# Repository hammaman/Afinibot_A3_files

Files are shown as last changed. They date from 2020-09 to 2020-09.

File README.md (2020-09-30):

# Afinibot_A3_files

The Afinibot A3 3D printer is a 3D printer in acrylic which has been classified as a Migbot Prusa i3 variant (see https://reprap.org/wiki/Migbot_Prusa_i3).

It appears to use a Melzi controller board (see https://www.reprap.org/wiki/Melzi).

Repository for Afinibot A3 files:
 - Original build instructions
 - FTDI USB drivers
  - A3 firmware from Afinibot forum (https://www.robotshop.com/community/forum/t/3d-printer-firmware/26569)

Plus additional STL files from redesign of X-Axis parts (based on those for Prusa i3 MK3S)

# Other useful information

I have found some firmware which I have not reviewed in a Github repository at https://github.com/Octane70/Repetier-Firmware-0.92.X.

There are some wordpress articles at https://electronicgeektips.wordpress.com/prusa-i3-auto-level-troubleshooting/

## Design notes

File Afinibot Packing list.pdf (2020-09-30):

Category | Name | Unit

Framework

Framework (Middle) | 1pcs | □ □
Framework (Left) | 1pcs | □ □
Framework (Right) | 1pcs | □ □
Base Frame Holder (Front) | 1pcs | □ □
Base Frame Holder (Back) | 1pcs | □ □
Framework Holder (top) | 2pcs | □ □
LCD Display Holder | 1pcs | □ □
Sliding Rod Restriction | 6pcs | □ □
Heating End | Print Platform (Assembled) Extruder (Assembled) | 1pcs 1pcs | □ □ □ □
X-axis | X-axis Motor Mount X-axis Pulley Mount X-axis Sliding Rod (Φ8/ 448mm) X-axis Timing Belt X-xis Limit Switch | 1set 1set 2pcs 1pcs 1pcs | □ □ □ □ □ □ □ □ □ □
Category | Name | Unit

Y-axis

Y-axis Motor Support | 1pcs | □ □
Y-axis Motor Holder | 1pcs | □ □
Y-axis Limit Switch Holder | 1pcs | □ □
Y-axis Motor(with 2GT Gear) | 1set | □ □
Y-axis Sliding Rod (Φ8/380mm) | 2pcs | □ □
Y-axis Limit Switch | 1pcs | □ □
Y-axis Timing Belt | 1pcs | □ □
Y-axis Belt Pulley Wheel | 1set | □ □

Z-axis

Z-axis Motor Support(Side) | 4pcs | □ □
Z-axis Motor Support(Top) | 2pcs | □ □
Z-axis Motor (With coupling) | 2pcs | □ □
Z-axis Screw Arbor (M8/322mm) | 2set | □ □
Z-axis Sliding Rod(Φ8/350mm) | 2pcs | □ □
Z-axis Limit Switch | 1pcs | □ □
Display | LCD Display & Key-press | 1set | □ □

Afinibot A3 3D printer part list

Electronic | Control Board Power Supply | 1pcs 1pcs | □ □ □ □
Wiring | DC Power Wire (Red&Black) Motor Wire X-axis limit switch Wire Y-axis limit switch Wire Z-axis limit switch Wire | 2pcs 4pcs 1pcs 1pcs 1pcs | □ □ □ □ □ □ □ □ □ □
Feeding Support | Frame Fixed Link Filament Support Frame Filament Support Tube | 2pcs 2pcs 1pcs | □ □ □ □ □ □

Accessory

Screw Arbor (Base) M8/400mm | 2pcs | □ □
TUS (M8/Transparent) | 5pcs | □ □
Copper Pillar | 4pcs | □ □
Flat-heat Cross-screw(M3*14mm) | 13pcs | □ □
Flat-heat Cross-screw(M3*20mm) | 2pcs | □ □
Round Head Screw(M3*20mm) | 46pcs | □ □
Inner Hexagon Screw(M3*10mm) | 15pcs | □ □
Inner Hexagon Screw(M3*20mm) | 3pcs | □ □
Inner Hexagon Screw(M3*30mm) | 2pcs | □ □
Tapping Screw(Black ,M2*14mm) | 2pcs | □ □
Nut (M8) | 12pcs | □ □
Nut (M3) | 45set | □ □
Cushion Ring (M8) | 12pcs | □ □
Cushion Ring (M3) | 10pcs | □ □
Nylon Cable Ties (Length 120mm) | 8pcs | □ □

Tools

USB Cable (150cm) | 1pcs | □ □
TF Card (4GB) | 1pcs | □ □
Tweezers | 1pcs | □ □
Diagonal Pliers | 1pcs | □ □
Hexagon Socket Key | 1set | □ □
Flat Blade Screwdriver | 1pcs | □ □
Crosshead Screwdriver | 1pcs | □ □

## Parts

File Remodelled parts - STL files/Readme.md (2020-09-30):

# Remodelled parts

The X-Axis left and right hand side parts supplied were not very good; and had cracked on my printer (probably as a result of having the extruder too low).

I have designed new parts (as I cannot find the original STL files anywhere online), based on the models for the Prusa i3 MK3S.

The Prusa i3 MK3S models are taken from https://www.prusa3d.com/prusa-i3-printable-parts/ and subject to the GNU GPL v3 licence.  These models have been adjusted for my personal use, and are shared subject to the terms of the licence.

The main adjustments made are as follows:
- the right hand x-axis idler is designed so that the two rods pass completely through it.  The holes may need to be slightly widened to make a tight fit, but also allow the rods to slide through without too much effort.
- a new part has been designed to attach to the right of the x-axis idler to hold the rods steady.  This connects using a M3 screw (30mm or longer) and a square M3 nut inserted into the slot in the x-axis idler.
- the left hand x-axis motor is designed so that the belt is set up quite tight, and then can be adjusted by inserting a M3 screw in the top.

As a result of the new parts, the alignment of the belt is slightly different:
- A new part is required to be inserted on the back of the extruder where the belt is attached, so that the belt runs in the same plane as the rods.
- Also, the z-axis switch needs to be further away from the frame, and a new part is required to act as a spacer.

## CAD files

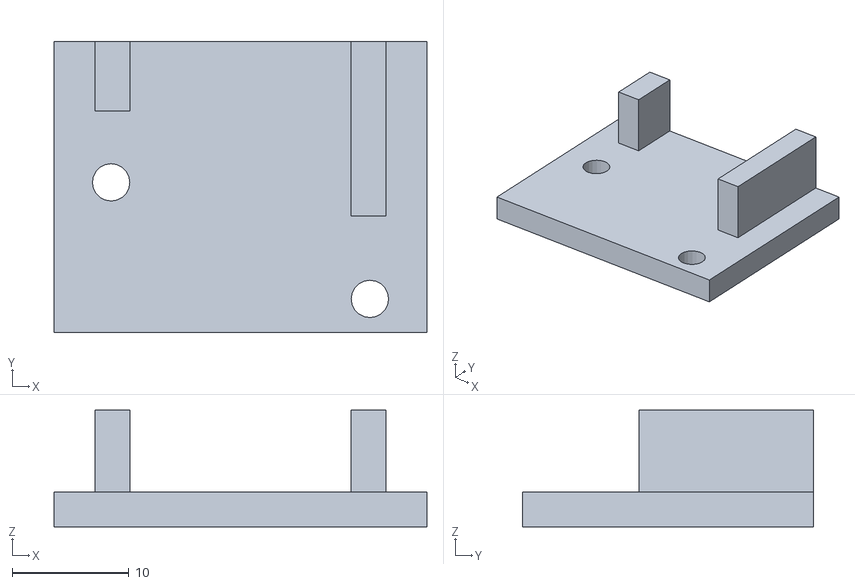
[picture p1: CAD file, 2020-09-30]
Remodelled parts - STL files/v3 Z Axis Switch Mount.stl
32.0 x 25.0 x 10.0

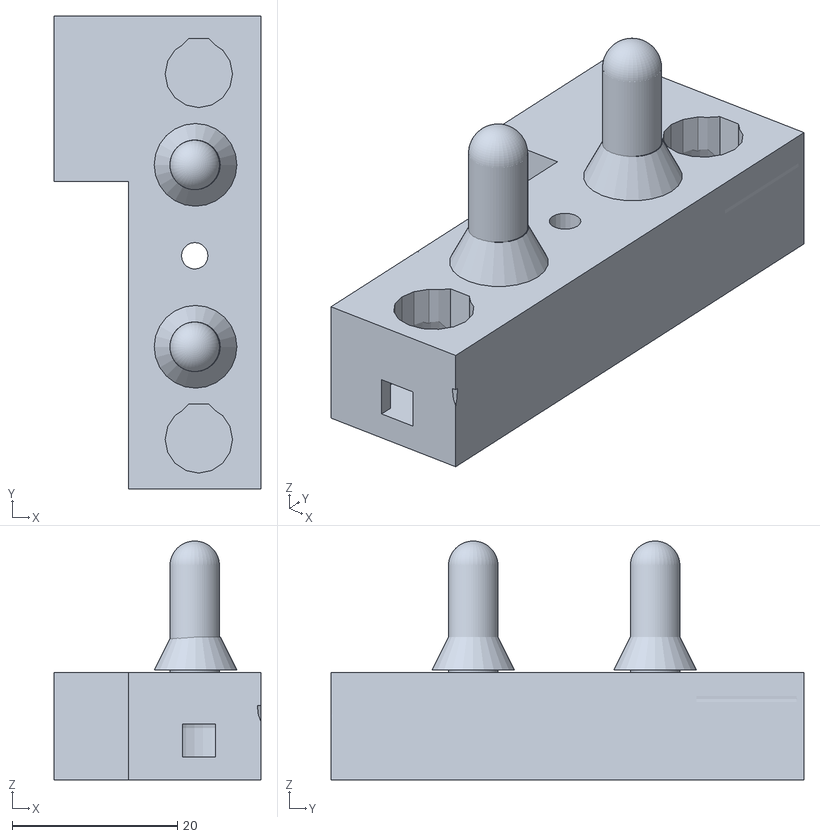
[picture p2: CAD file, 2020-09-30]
Remodelled parts - STL files/v3 End stop for X Idler with laser mount.stl
25.0 x 57.2 x 28.9

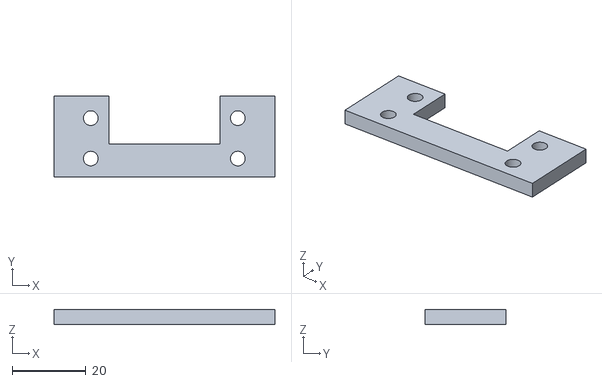
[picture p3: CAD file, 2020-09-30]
Remodelled parts - STL files/3D printer spacer v3.stl
60.1 x 22.0 x 4.00

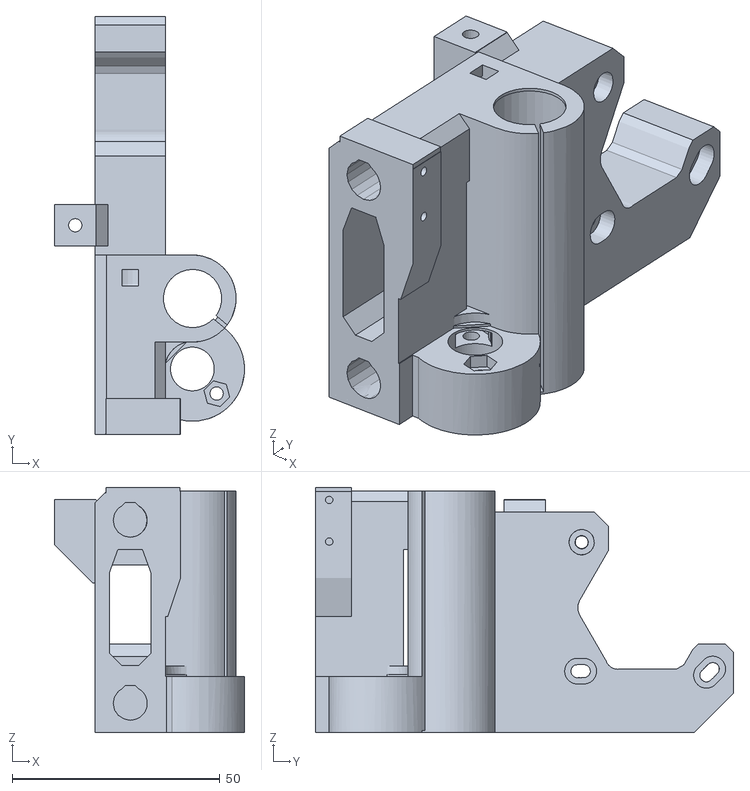
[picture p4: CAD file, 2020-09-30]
Remodelled parts - STL files/v6 Adjusted Prusa i3 X Motor.stl
45.7 x 100.5 x 58.9

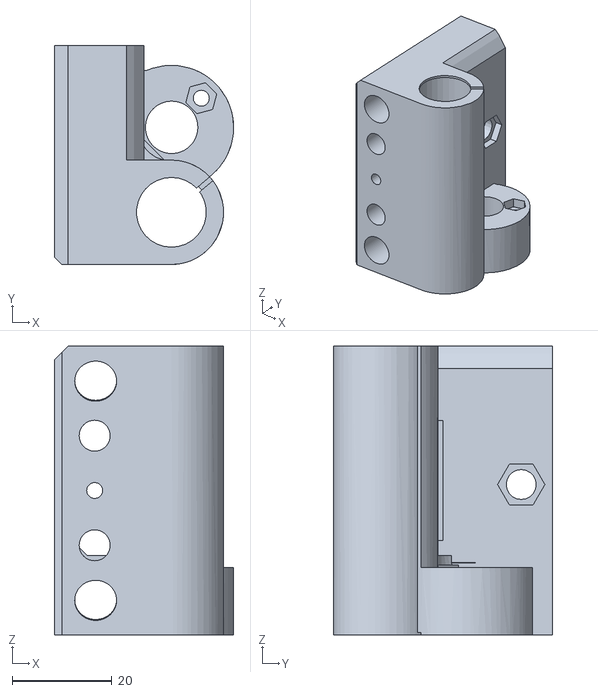
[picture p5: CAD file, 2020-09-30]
Remodelled parts - STL files/v7 Adjusted Prusa i3 x-axis idler.stl
36.0 x 44.0 x 58.0

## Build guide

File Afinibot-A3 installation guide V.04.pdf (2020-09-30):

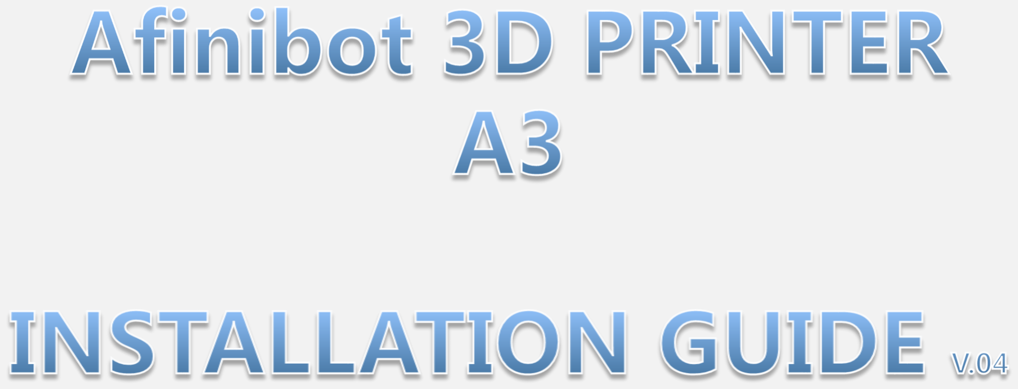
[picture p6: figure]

## Classification Of Screws

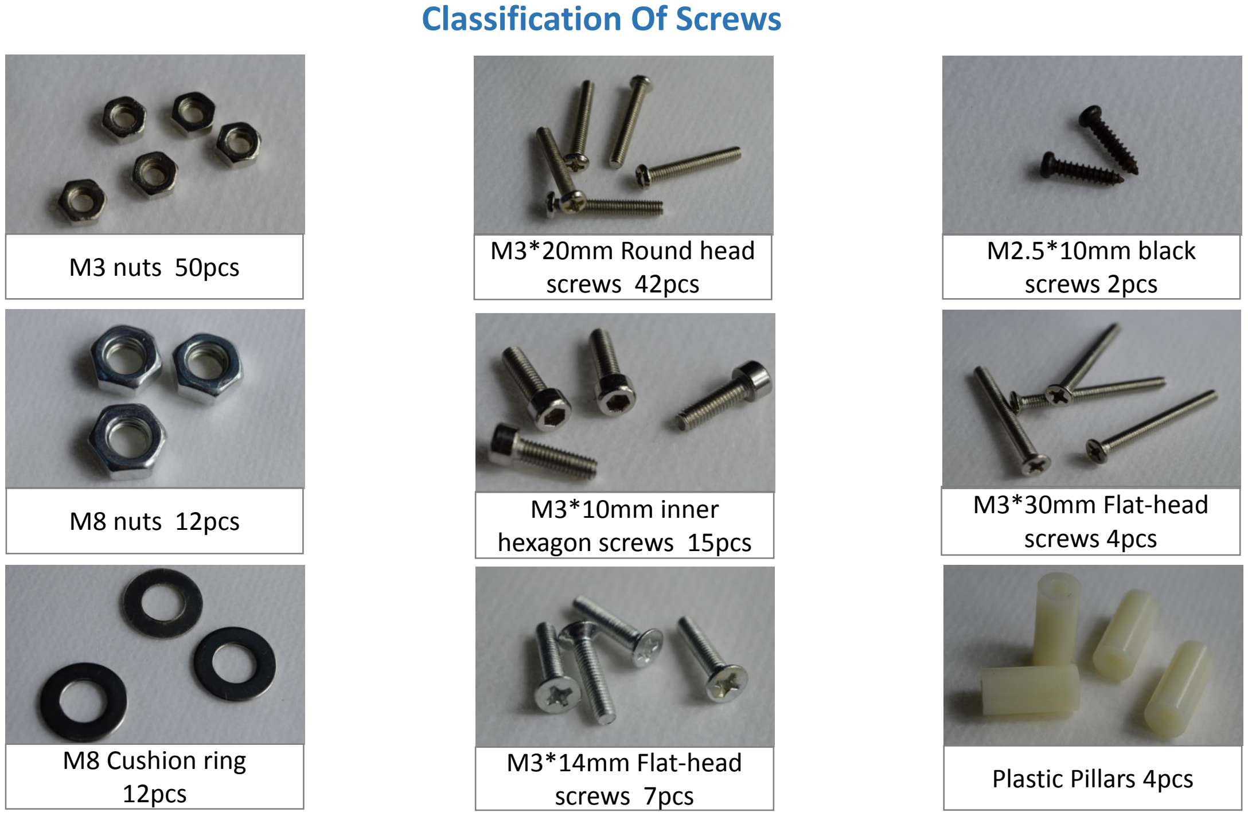
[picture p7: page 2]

M3 nuts 50pcs | M3*20mm Round head screws 42pcs

M2.5*10mm black
screws 2pcs

M3*10mm inner
hexagon screws 15pcs

M8 nuts 12pcs

M8 Cushion ring
12pcs | Plastic Pillars 4pcs M3*14mm Flat-head
screws 7pcs

M3*30mm Flat-head
screws 4pcs

## Step 1 Assemble Y-axis Motor

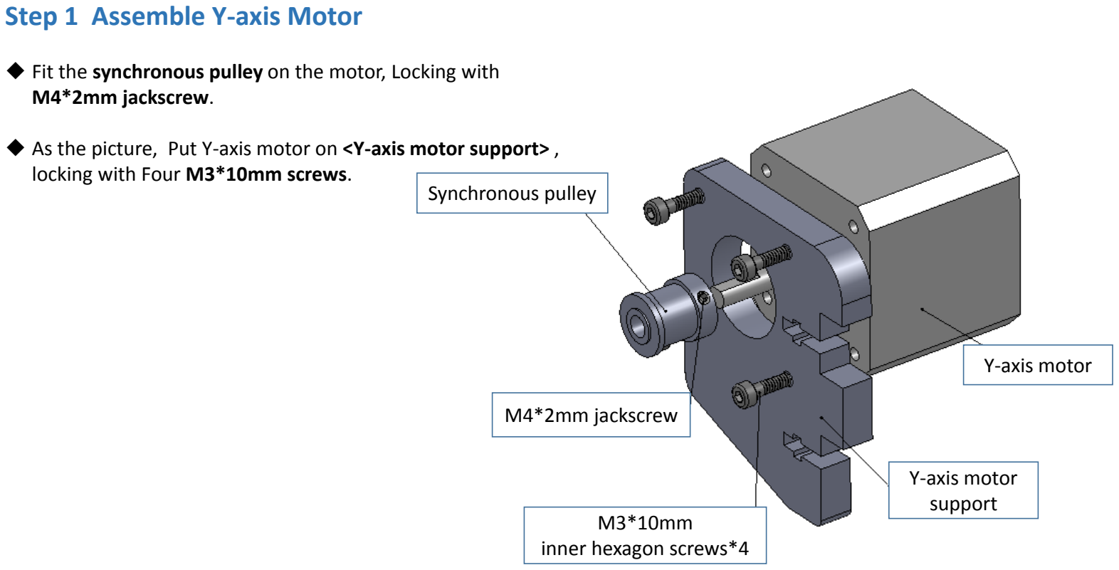
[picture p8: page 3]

M3*10mm
inner hexagon screws*4

Y-axis motor
support

Y-axis motor

M4*2mm jackscrew

Synchronous pulley

- Fit the synchronous pulley on the motor, Locking with M4*2mm jackscrew.
- As the picture, Put Y-axis motor on <Y-axis motor support> , locking with Four M3*10mm screws.

## Step 2 Assemble Y-axis Limit switch

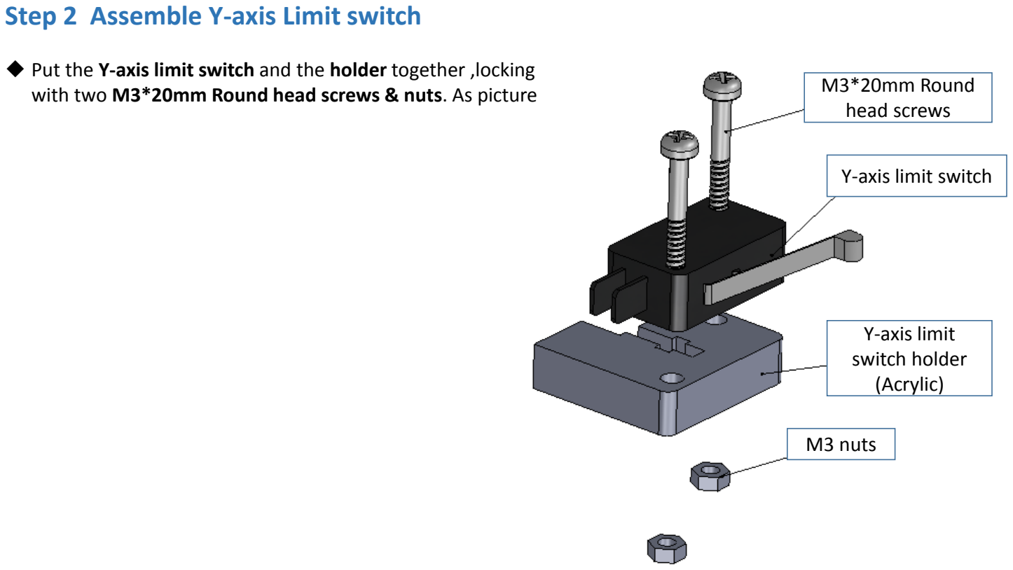
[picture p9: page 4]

- Put the Y-axis limit switch and the holder together ,locking
with two M3*20mm Round head screws & nuts. As picture | M3*20mm Round
| head screws
| Y-axis limit switch

Y-axis limit
switch holder
(Acrylic)

M3 nuts

## Step 3 Assemble Base Frame Holder_Back

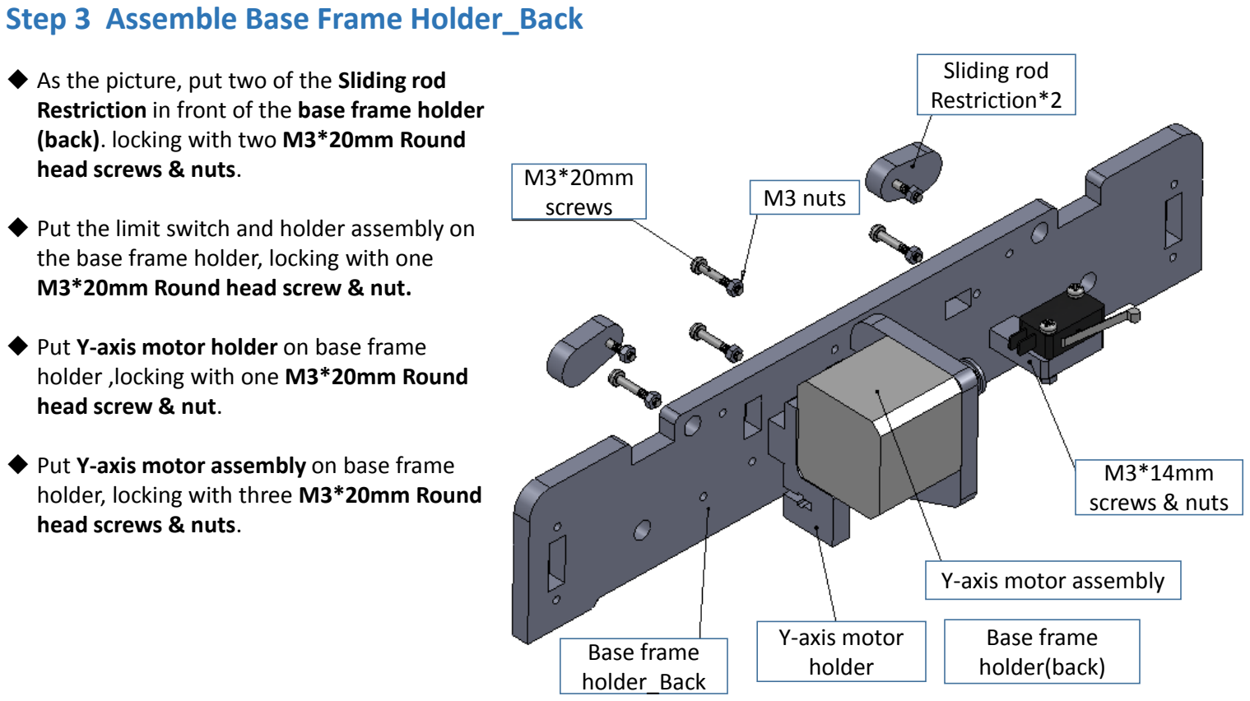
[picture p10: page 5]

Y-axis motor assembly

Base frame
holder(back)

Sliding rod
Restriction*2

M3*20mm
screws

M3*14mm
screws & nuts

Y-axis motor
holder Base frame
holder_Back

M3 nuts

- As the picture, put two of the Sliding rod Restriction in front of the base frame holder (back). locking with two M3*20mm Round head screws & nuts.
- Put the limit switch and holder assembly on the base frame holder, locking with one M3*20mm Round head screw & nut.
- Put Y-axis motor holder on base frame holder ,locking with one M3*20mm Round head screw & nut.
- Put Y-axis motor assembly on base frame holder, locking with three M3*20mm Round head screws & nuts.

## Step 4 Assemble Base Frame Holder_Front

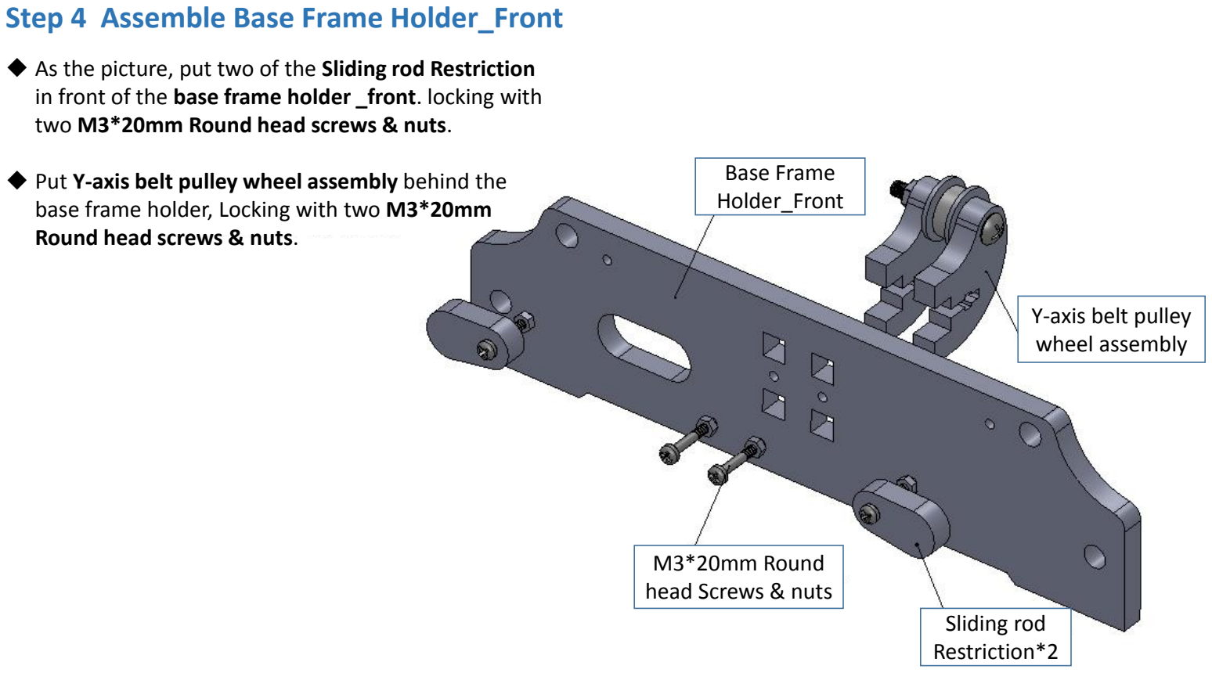
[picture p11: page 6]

Sliding rod
Restriction*2

M3*20mm Round
head Screws & nuts

Y-axis belt pulley
wheel assembly

Base Frame
Holder_Front
- As the picture, put two of the Sliding rod Restriction in front of the base frame holder _front. locking with two M3*20mm Round head screws & nuts.
- Put Y-axis belt pulley wheel assembly behind the base frame holder, Locking with two M3*20mm Round head screws & nuts.

## Step 5 Assemble Z-axis motor

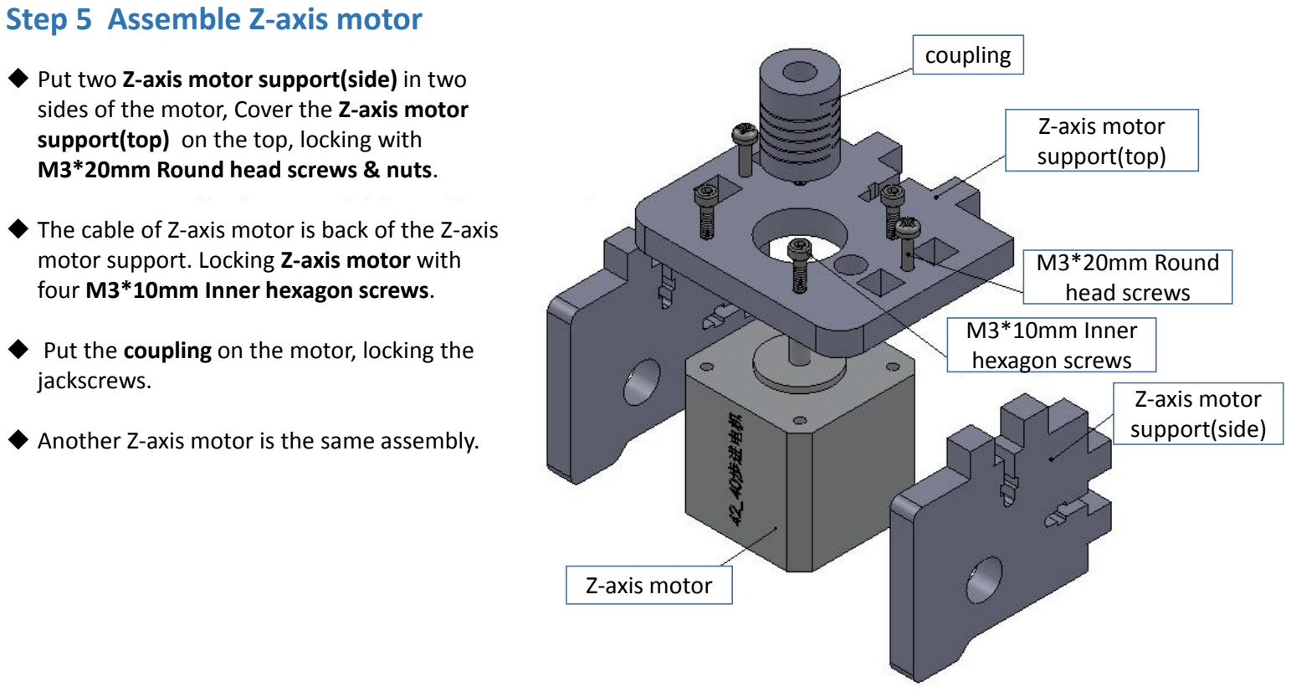
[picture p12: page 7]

coupling

M3*20mm Round
head screws
M3*10mm Inner
hexagon screws
Z-axis motor
support(side)

Z-axis motor
support(top)

Z-axis motor

- Put two Z-axis motor support(side) in two sides of the motor, Cover the Z-axis motor support(top) on the top, locking with M3*20mm Round head screws & nuts.
- The cable of Z-axis motor is back of the Z-axis motor support. Locking Z-axis motor with four M3*10mm Inner hexagon screws.
- Put the coupling on the motor, locking the jackscrews.
- Another Z-axis motor is the same assembly.

Step 6 Assemble Cooling fan | The cooling fan wire

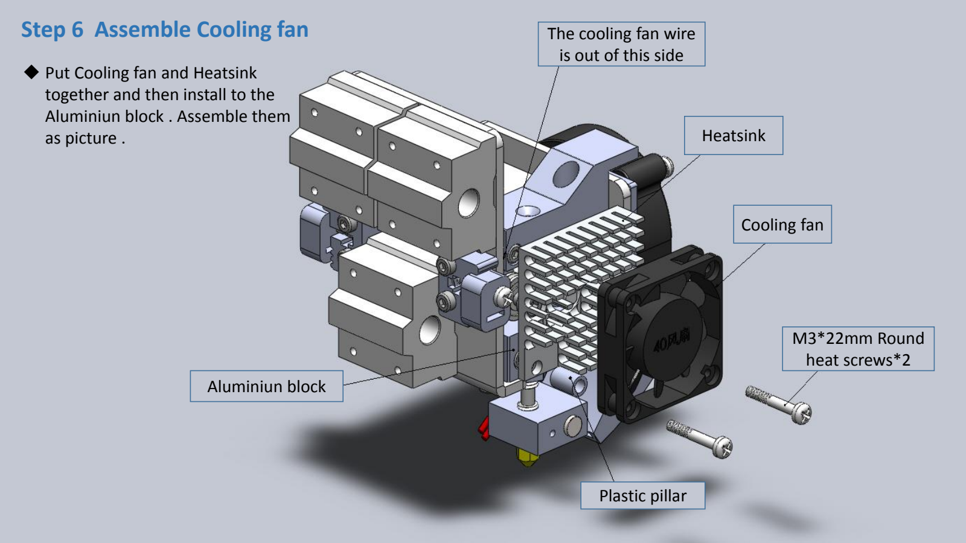
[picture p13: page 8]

is out of this side
- Put Cooling fan and Heatsink
together and then install to the
Aluminiun block . Assemble them
as picture . | Heatsink

Cooling fan

M3*22mm Round
heat screws*2
Aluminiun block

Plastic pillar

## Step 7 Assemble Z-axis

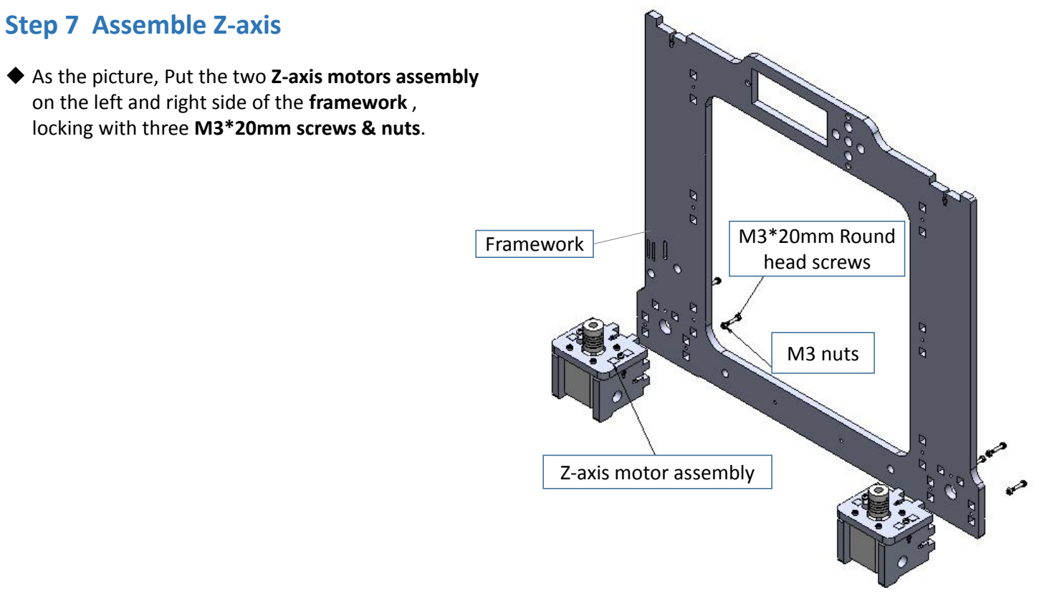
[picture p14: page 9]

Z-axis motor assembly

Framework | M3*20mm Round head screws

M3 nuts

- As the picture, Put the two Z-axis motors assembly on the left and right side of the framework , locking with three M3*20mm screws & nuts.

## Step 8 Assemble Framework

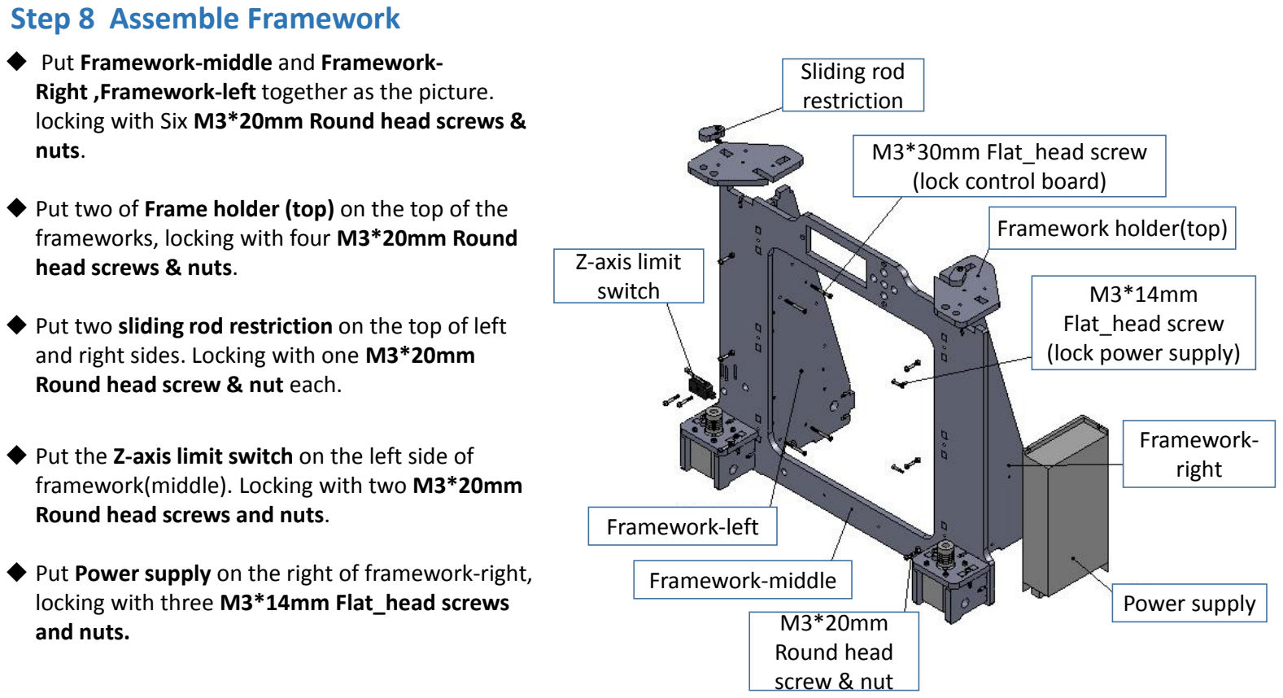
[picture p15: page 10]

Sliding rod
restriction

Framework holder(top)

Framework-right

Power supply

Framework-middle

Framework-left

M3*20mm
Round head
screw & nut

M3*14mm
Flat_head screw
(lock power supply)

M3*30mm Flat_head screw
(lock control board)

Z-axis limit
switch
- Put Framework-middle and Framework-Right ,Framework-left together as the picture. locking with Six M3*20mm Round head screws & nuts.
- Put two of Frame holder (top) on the top of the frameworks, locking with four M3*20mm Round head screws & nuts.
- Put two sliding rod restriction on the top of left and right sides. Locking with one M3*20mm Round head screw & nut each.
- Put the Z-axis limit switch on the left side of framework(middle). Locking with two M3*20mm Round head screws and nuts.
- Put Power supply on the right of framework-right, locking with three M3*14mm Flat_head screws and nuts.

## Step 9 Install Base frame holder_Back

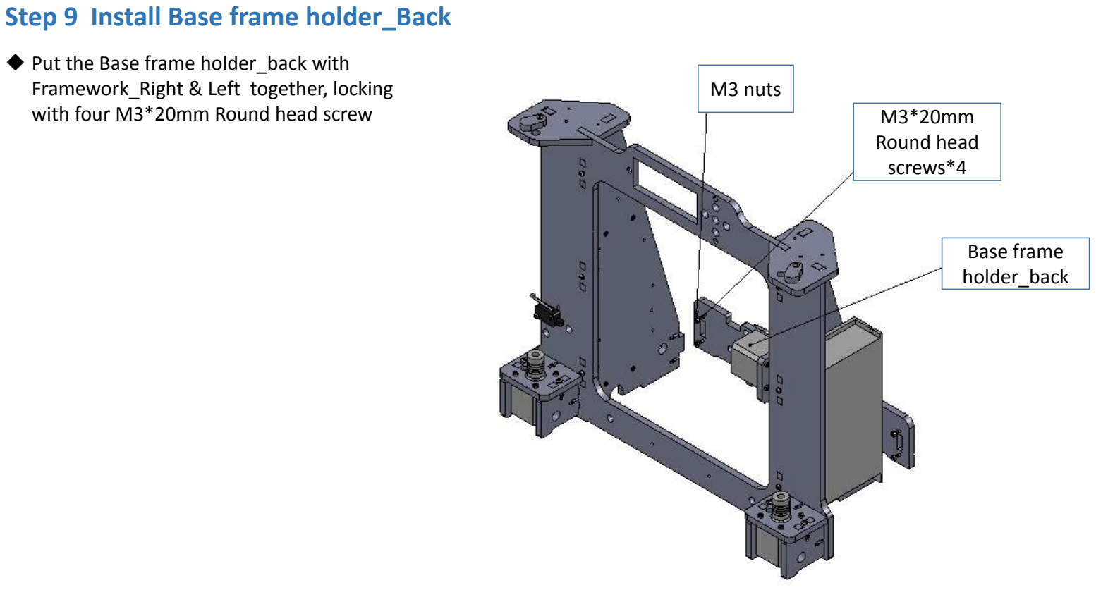
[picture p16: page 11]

Base frame
holder_back

M3*20mm
Round head
screws*4

M3 nuts

- Put the Base frame holder_back with Framework_Right & Left together, locking with four M3*20mm Round head screw

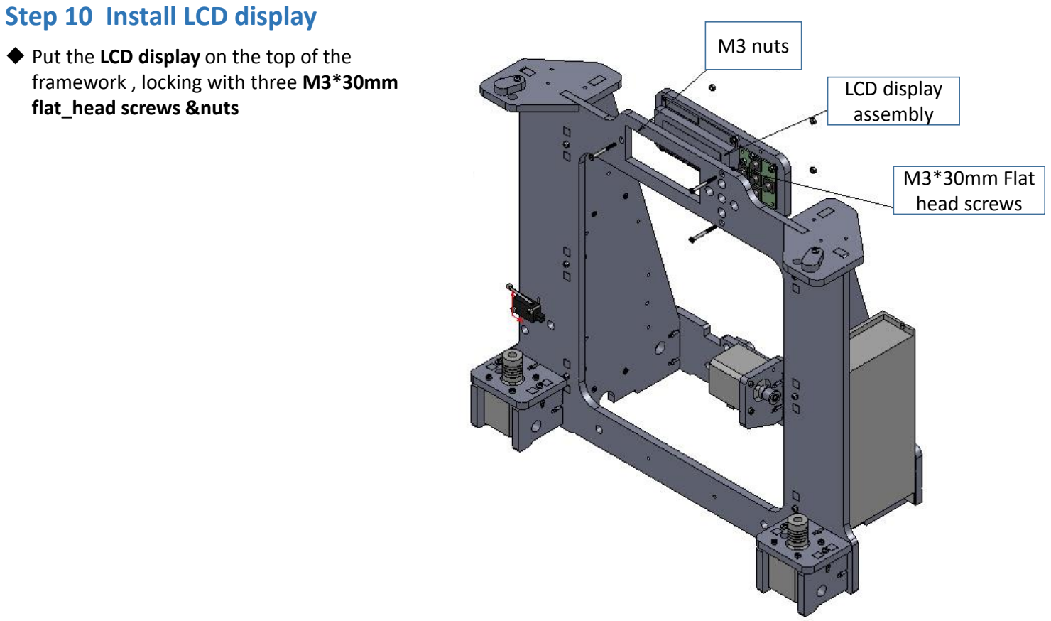
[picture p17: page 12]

Step 10 Install LCD display | M3 nuts Put the LCD display on the top of the

framework , locking with three M3*30mm
flat_head screws &nuts

LCD display
assembly

M3*30mm Flat
head screws

## Step 11 Install Base Frame Holder_Front

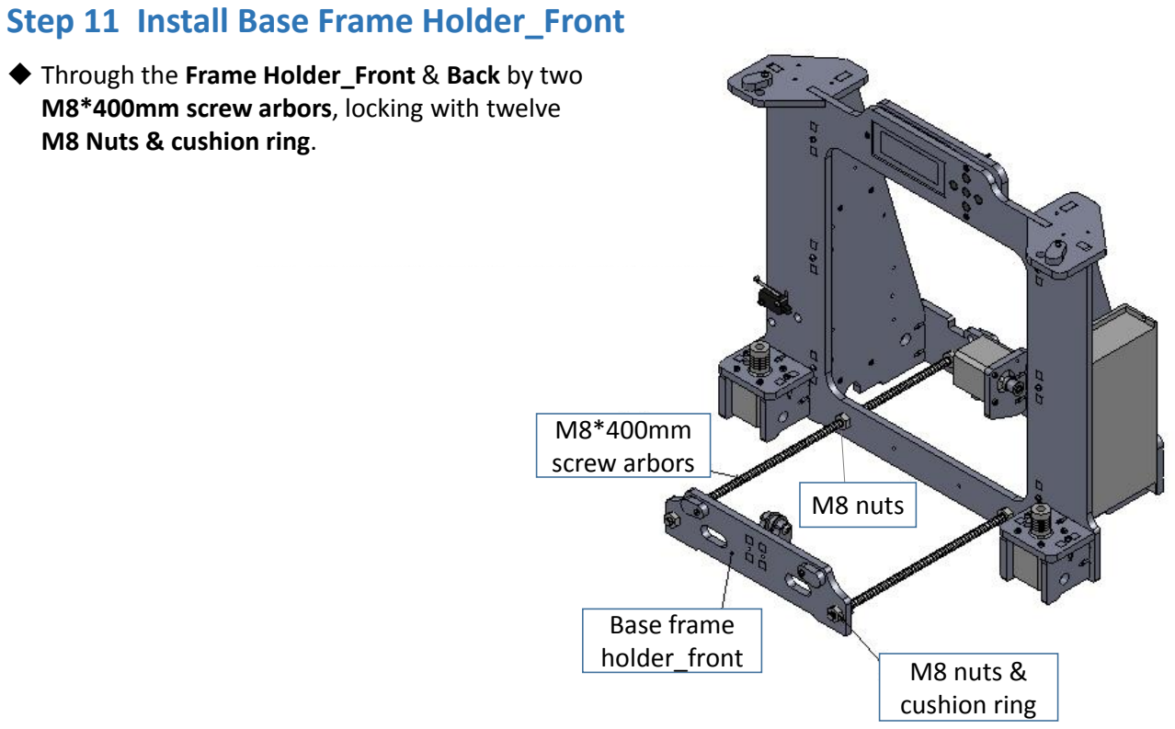
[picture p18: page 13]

M8 nuts &
cushion ring

M8*400mm
screw arbors

Base frame
holder_front

M8 nuts

- Through the Frame Holder_Front & Back by two M8*400mm screw arbors, locking with twelve M8 Nuts & cushion ring.

## Step 12 Instal Platform Assembly

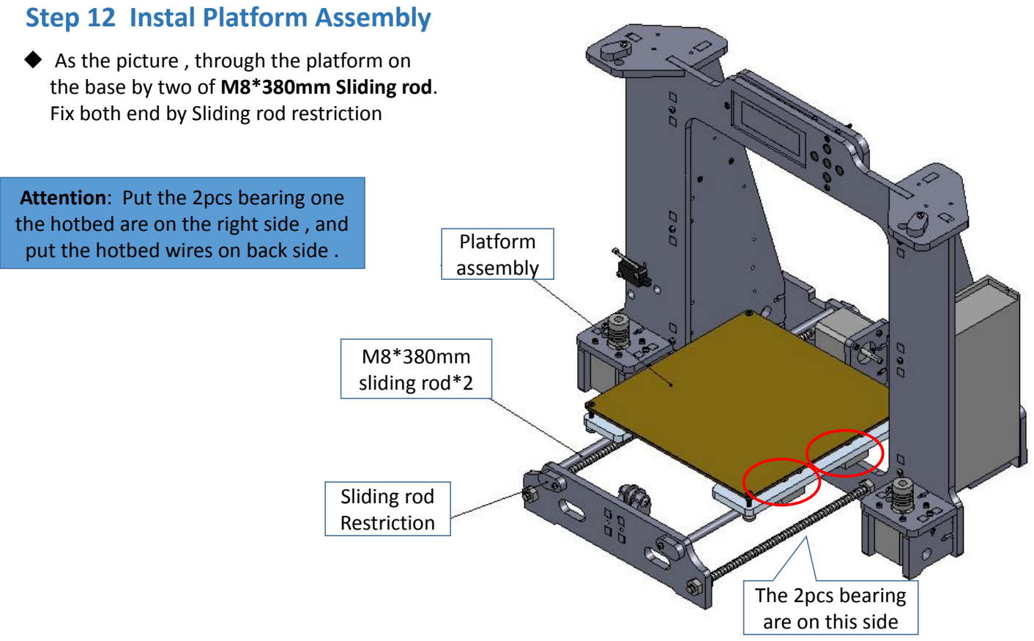
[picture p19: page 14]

Platform
assembly

M8*380mm
sliding rod*2

Sliding rod
Restriction
- As the picture , through the platform on the base by two of M8*380mm Sliding rod. Fix both end by Sliding rod restriction

The 2pcs bearing
are on this side

Attention: Put the 2pcs bearing one the hotbed are on the right side , and put the hotbed wires on back side .

## Step 13 Instal Y-axis Timing belt

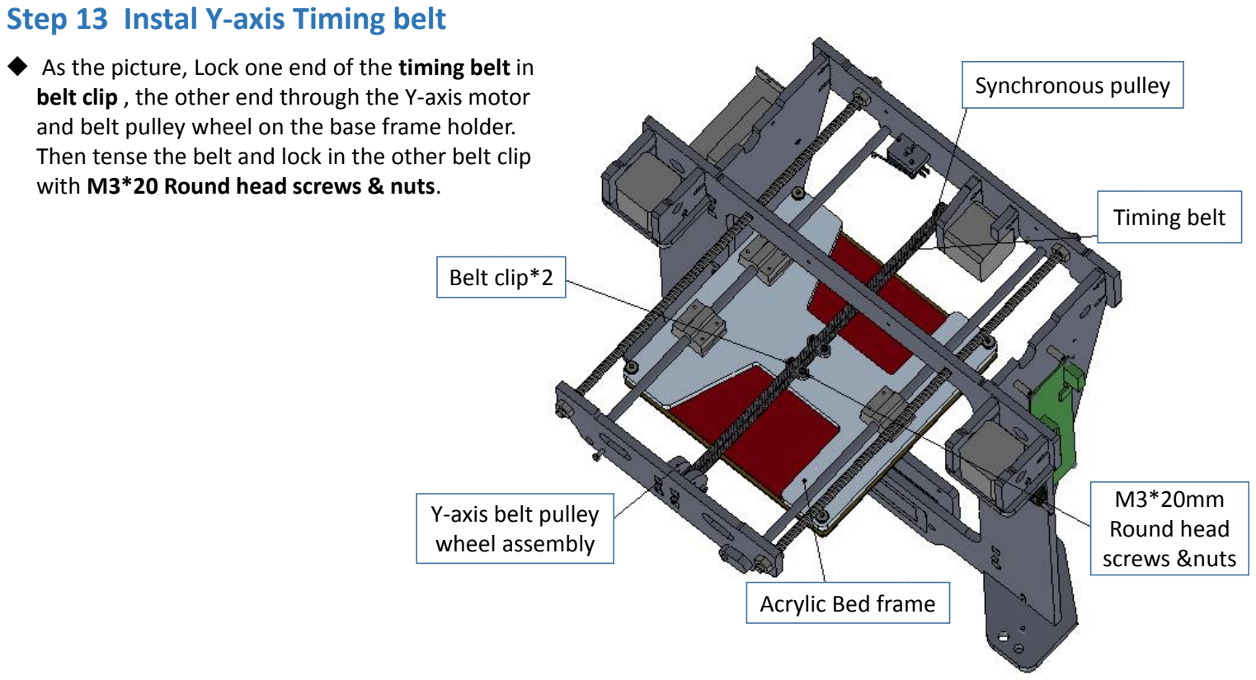
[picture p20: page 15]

Acrylic Bed frame

Timing belt

Belt clip*2

M3*20mm
Round head
screws &nuts

Synchronous pulley

Y-axis belt pulley
wheel assembly
- As the picture, Lock one end of the timing belt in belt clip , the other end through the Y-axis motor and belt pulley wheel on the base frame holder. Then tense the belt and lock in the other belt clip with M3*20 Round head screws & nuts.

## Step 14 Instal X-axis Extruder Assembly

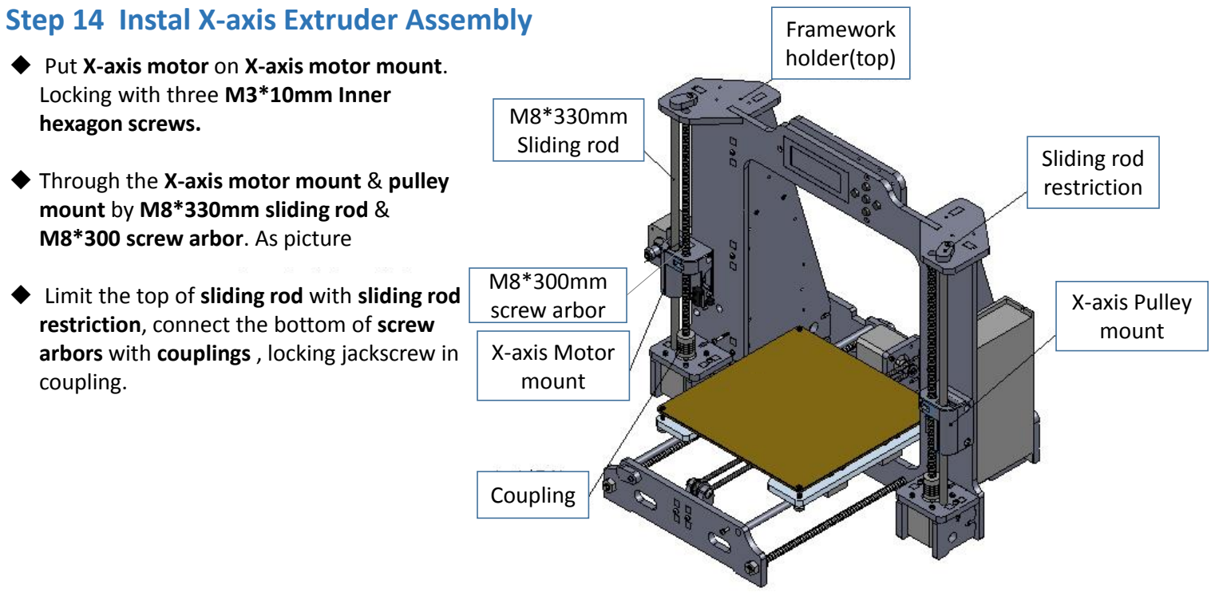
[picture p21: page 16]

Sliding rod
restriction

Framework
holder(top)

M8*330mm
Sliding rod

Coupling

M8*300mm
screw arbor | X-axis Pulley
| mount
X-axis Motor
mount
- Put X-axis motor on X-axis motor mount. Locking with three M3*10mm Inner hexagon screws.
- Through the X-axis motor mount & pulley mount by M8*330mm sliding rod & M8*300 screw arbor. As picture
- Limit the top of sliding rod with sliding rod restriction, connect the bottom of screw arbors with couplings , locking jackscrew in coupling.

Step 15 Assemble X-axis | X-axis motor

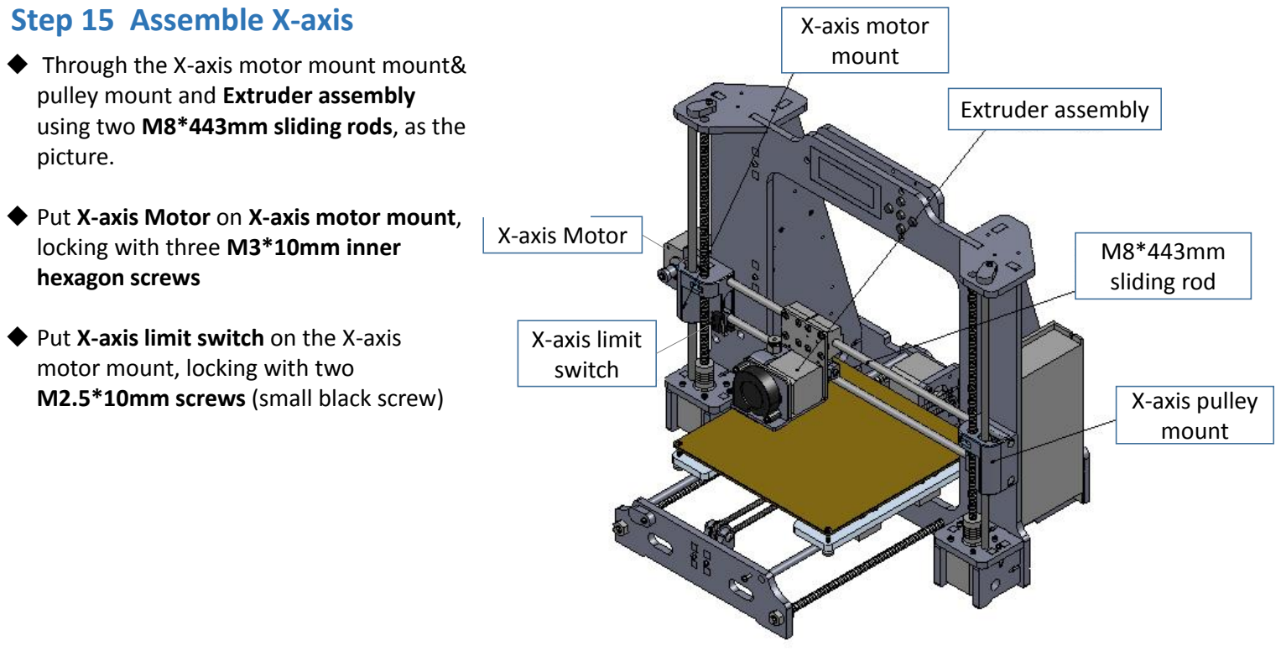
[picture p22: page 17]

mount

X-axis pulley
mount

M8*443mm
sliding rod

Extruder assembly

X-axis limit
switch

X-axis Motor

- Through the X-axis motor mount mount& pulley mount and Extruder assembly using two M8*443mm sliding rods, as the picture.
- Put X-axis Motor on X-axis motor mount, locking with three M3*10mm inner hexagon screws
- Put X-axis limit switch on the X-axis motor mount, locking with two M2.5*10mm screws (small black screw)

## Step 16 Instal X-axis Timing Belt

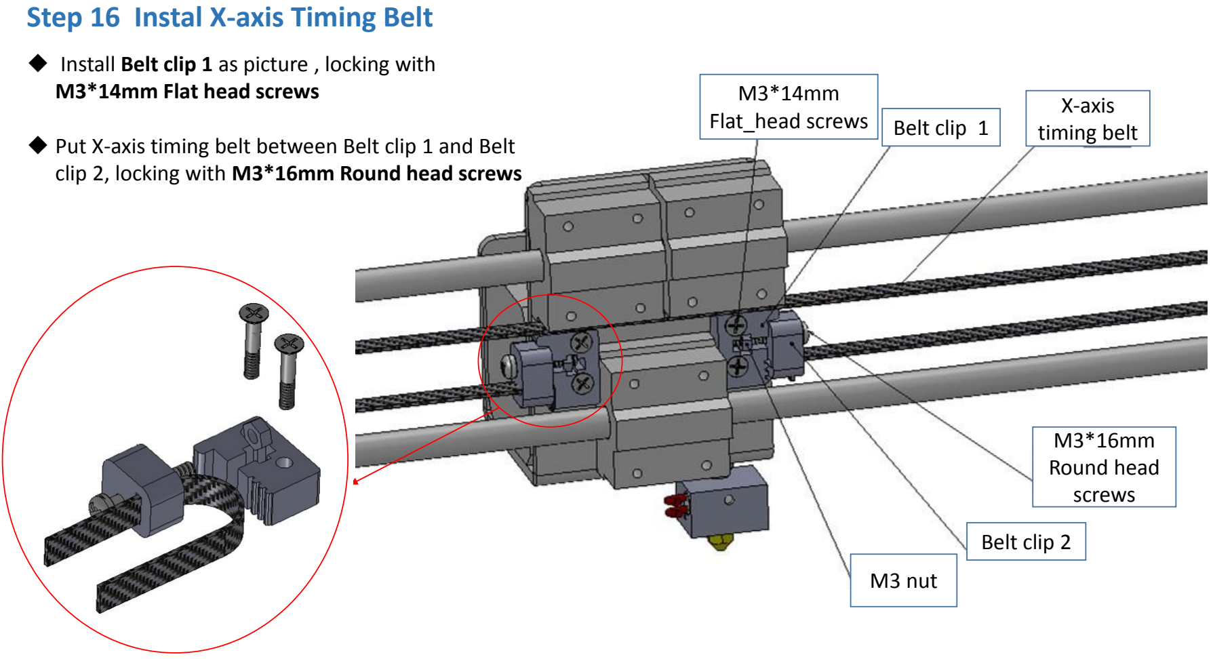
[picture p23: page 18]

X-axis
timing belt

M3*14mm
Flat_head screws

Belt clip 2

Belt clip 1

M3 nut

M3*16mm
Round head
screws
- Install Belt clip 1 as picture , locking with
M3*14mm Flat head screws
- Put X-axis timing belt between Belt clip 1 and Belt clip 2, locking with M3*16mm Round head screws

## Step 17 Control Board Wiring Diagram

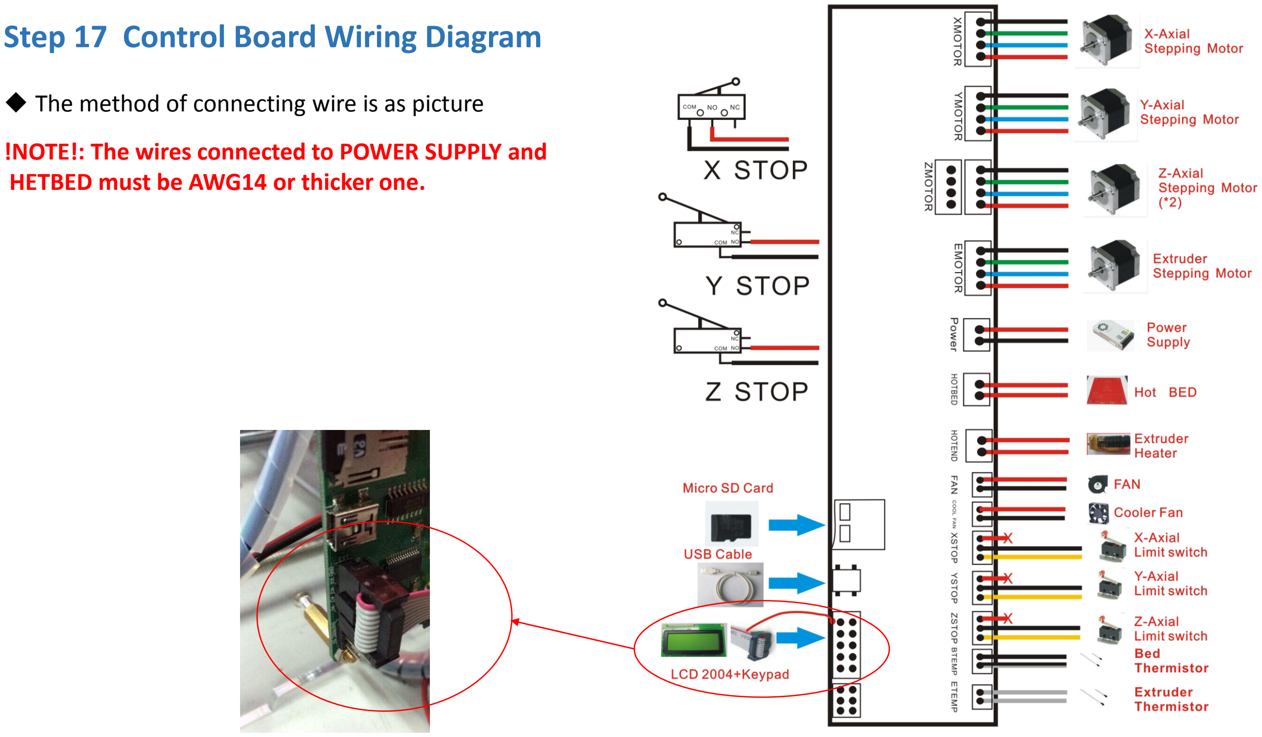
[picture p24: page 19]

- The method of connecting wire is as picture

!NOTE!: The wires connected to POWER SUPPLY and HETBED must be AWG14 or thicker one.

## Step 18 Install PCBA Control Board

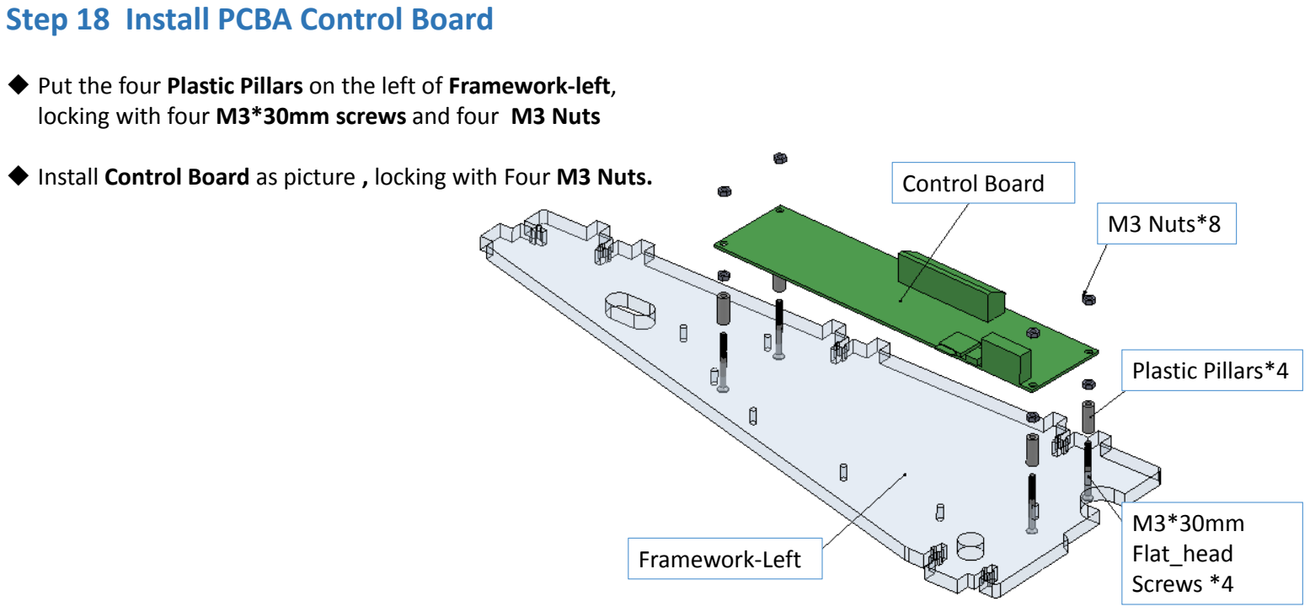
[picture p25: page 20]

- Put the four Plastic Pillars on the left of Framework-left,
locking with four M3*30mm screws and four M3 Nuts
- Install Control Board as picture , locking with Four M3 Nuts. | Control Board

M3 Nuts*8

Plastic Pillars*4

M3*30mm
Flat_head
Screws *4

Framework-Left

## Step 19 AC Power Connector Wiring Diagram

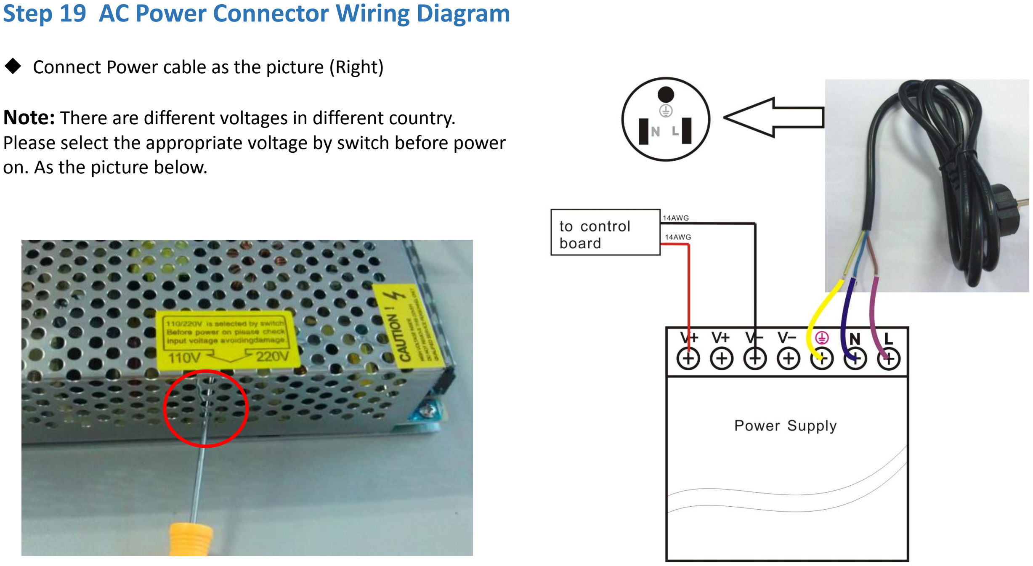
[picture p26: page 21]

- Connect Power cable as the picture (Right)

Note: There are different voltages in different country. Please select the appropriate voltage by switch before power on. As the picture below.

## Step 20 Assemble Filament Feeder

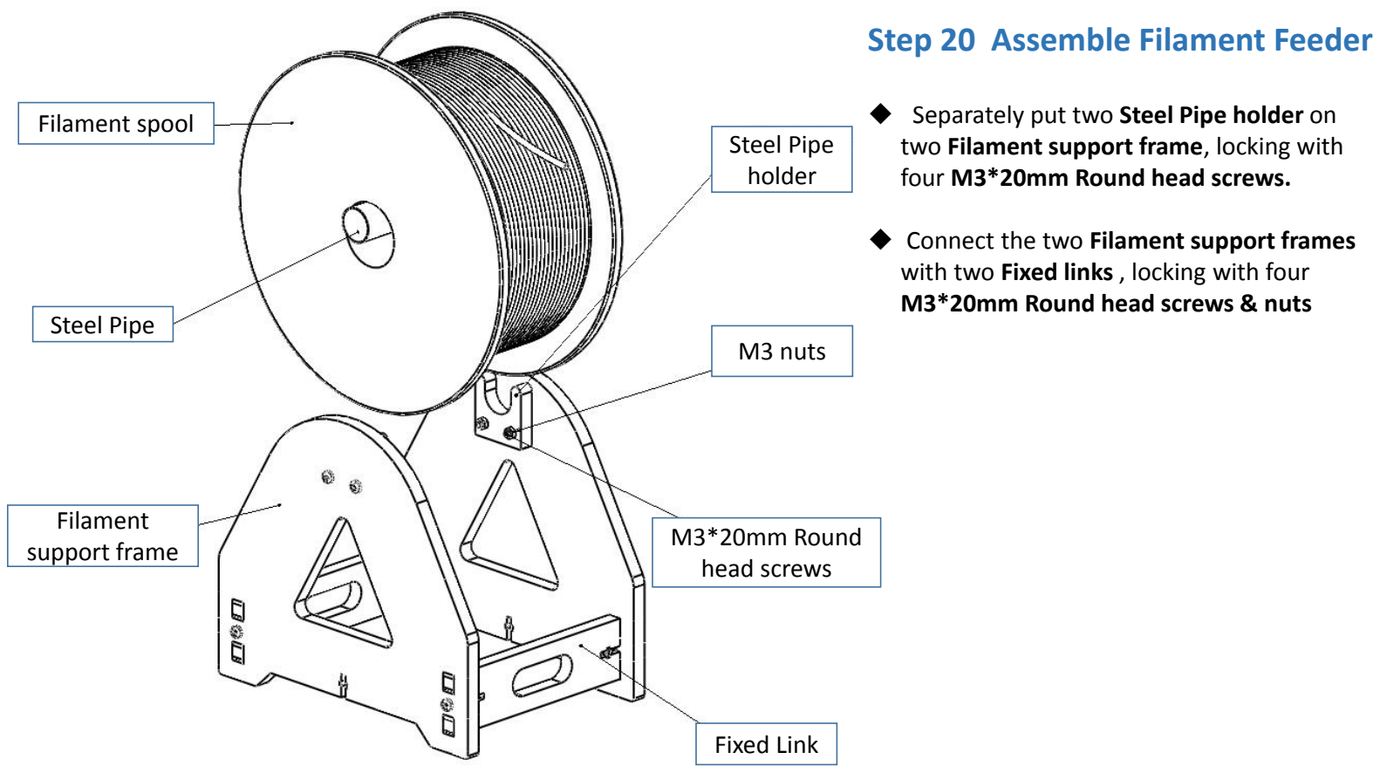
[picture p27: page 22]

Filament spool

Filament
support frame

Fixed Link

Steel Pipe

M3*20mm Round
head screws

M3 nuts

Steel Pipe
holder
- Separately put two Steel Pipe holder on two Filament support frame, locking with four M3*20mm Round head screws.
- Connect the two Filament support frames with two Fixed links , locking with four M3*20mm Round head screws & nuts

## Installation Finished

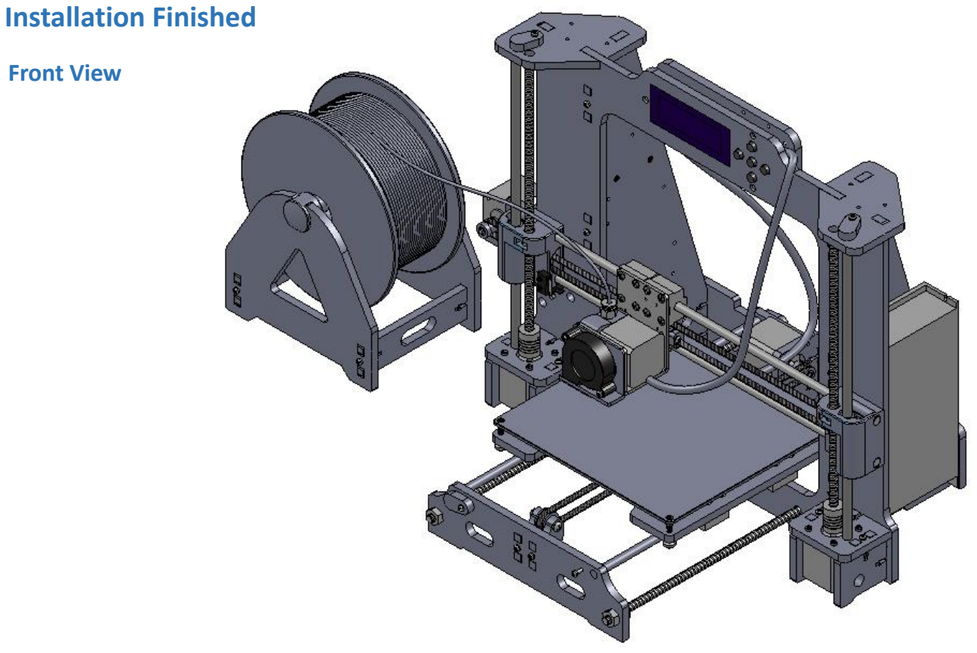
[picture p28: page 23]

Front View

## Installation Finished

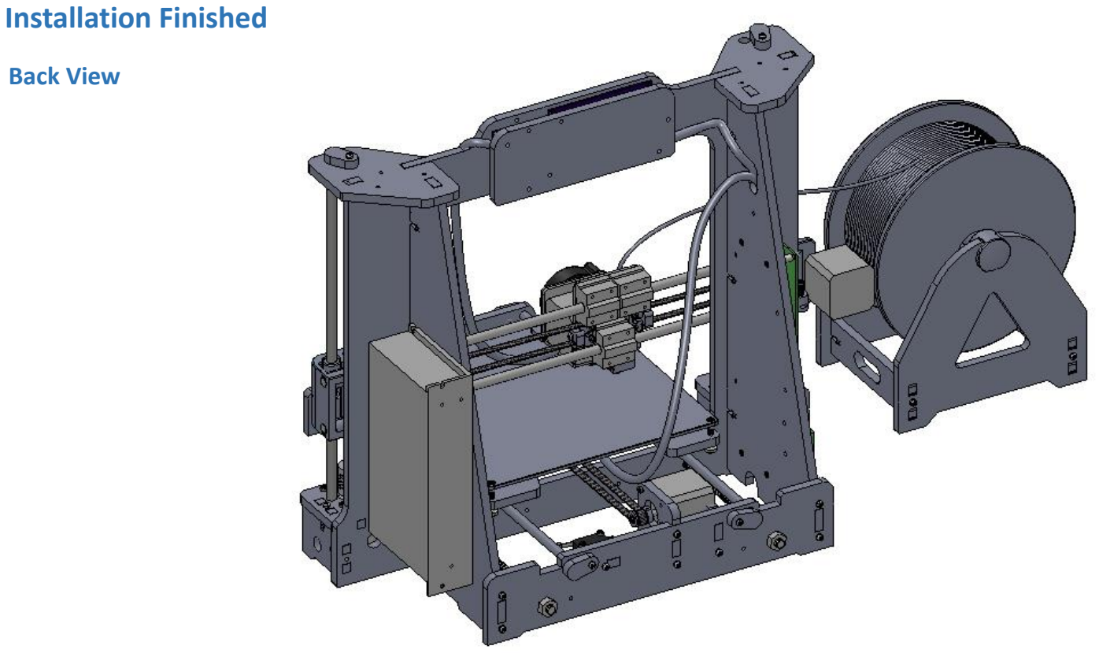
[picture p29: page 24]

Back View

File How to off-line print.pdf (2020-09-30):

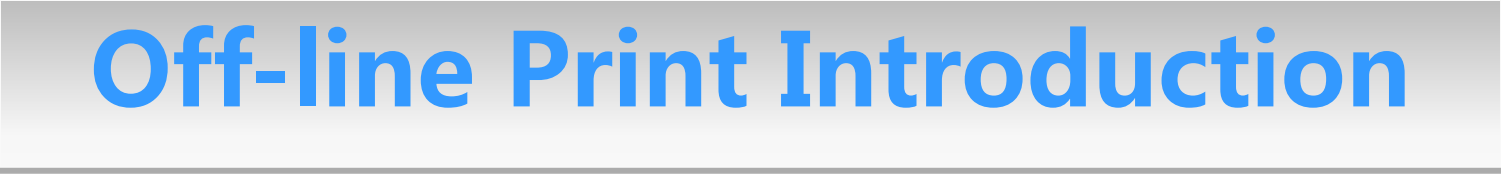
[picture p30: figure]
Off-line Print Introduction

Insert Micro SD card to the machine which had stored the Gcode files .

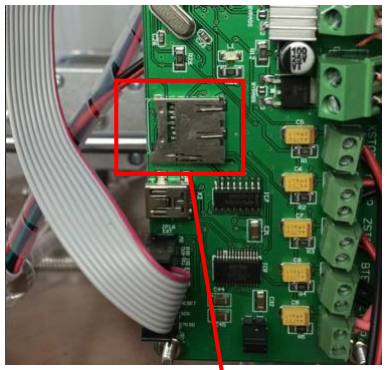
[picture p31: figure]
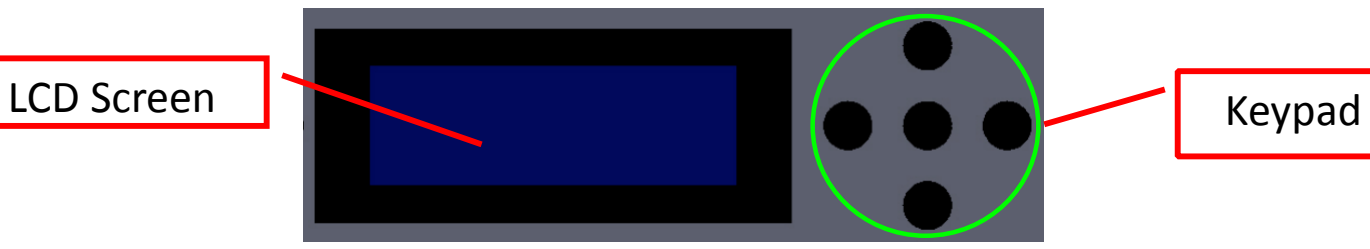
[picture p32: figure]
Keypad LCD Screen

Key name | Key function | Remark
Left | Back To Previous Menu
Right | Go to next menu/Enter
Up | Menu Up / Plus
Down | Menu Down / Minus
Middle | Start menu

insert Micro SD card which had stored G-code file

The Micro SD card slot is on the left of the control board.

LCD screen and Key-press function instruction .

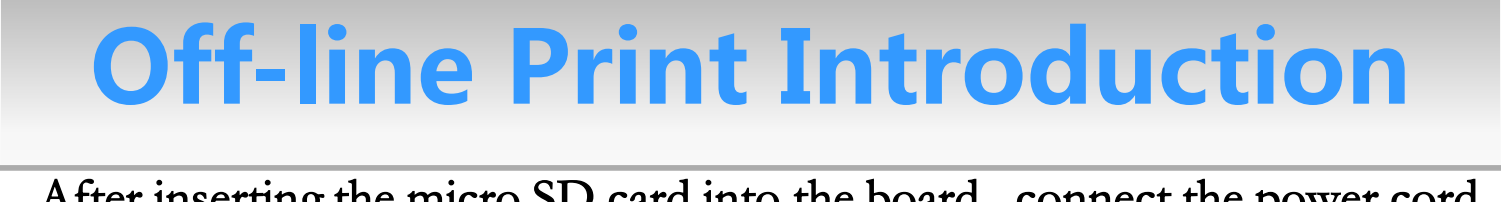
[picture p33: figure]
Off-line Print Introduction

After inserting the micro SD card into the board , connect the power cord,

### then you can operate the machine with key and display. Show as below:

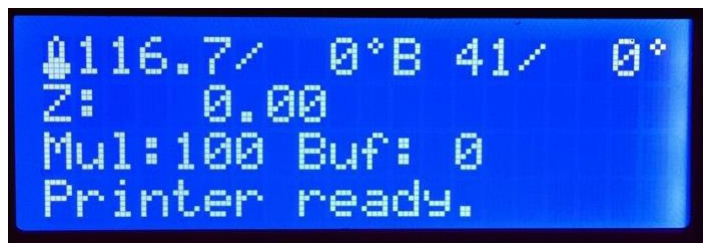
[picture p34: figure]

You’ll see the “monitoring interface” first.

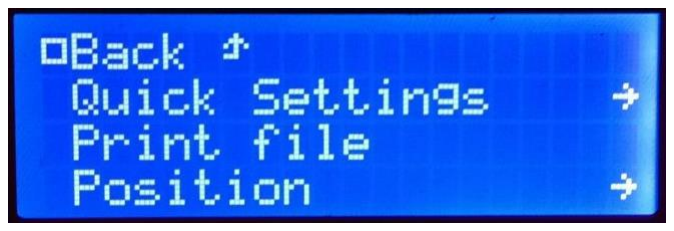
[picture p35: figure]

Press menu button go into
“menu screen”.

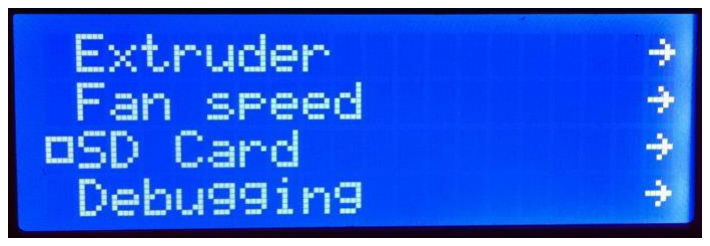
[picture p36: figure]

Press Down key after into
menu, then you will see
“SD card”

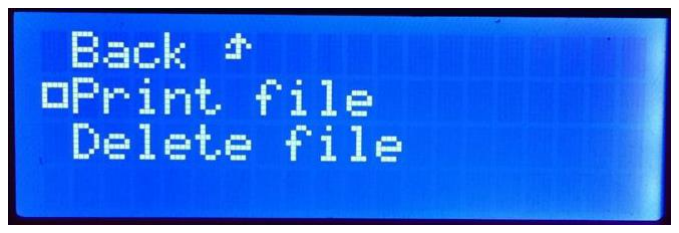
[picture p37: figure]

Press Right key and select “SD card”. and then press
Right key select “Print file”.

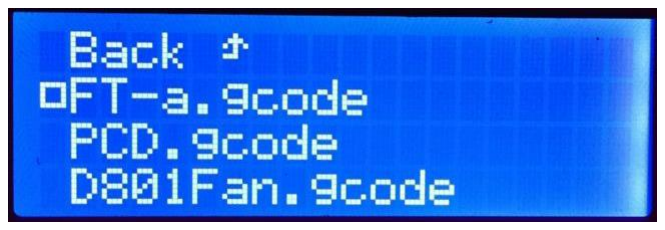
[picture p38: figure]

Select a Gcode file which
want to print, then press
Right key to start print.

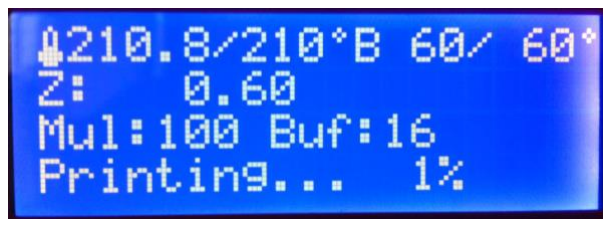
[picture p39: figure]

You’ll see the monitor
interface when printing, it shows Nozzle and Hot-Bed
temperature, and the printing completion rate.

If want to “Pause Print” or “Stop Print”, Press Manu
key ,select “SD card” ,then the screen will appear the interface as left picture . Select Pause or Stop , press Right key to confirm.

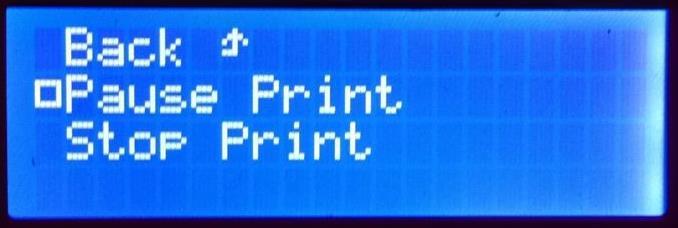
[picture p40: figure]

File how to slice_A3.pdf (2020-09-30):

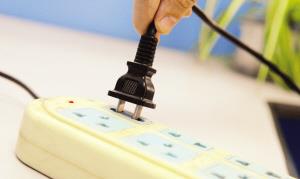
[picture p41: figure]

1. Connect the machine to
the electricity supply.

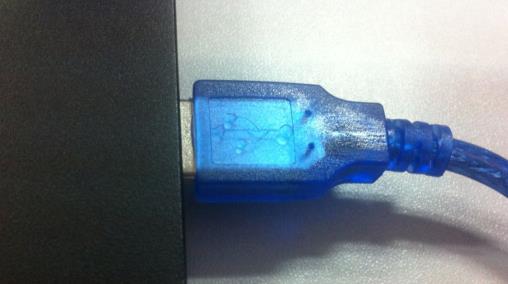
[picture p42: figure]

2.Plug one end of USB cable into Computer

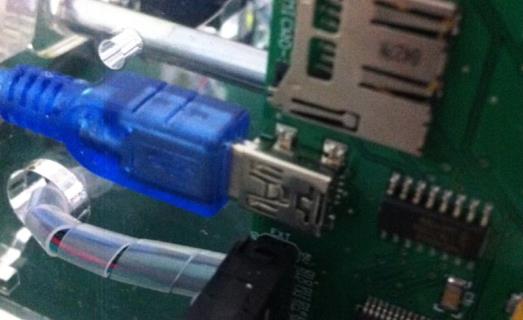
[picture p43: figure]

3. Plug another end into
machine

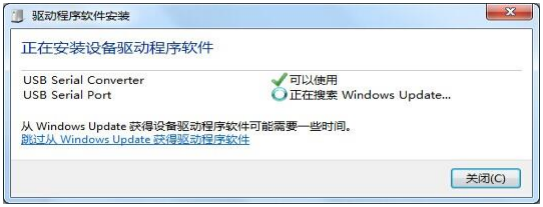
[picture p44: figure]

1. System prompted the USB driver is installing

The firmware is optimized by my company, and then loaded on mainboard , please do not upgrade the firmware by yourself.

After the USB cable plugged, the USB driver will auto-install on Win7 system, as picture below

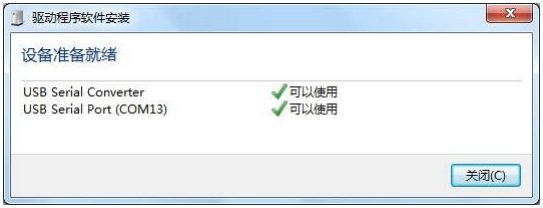
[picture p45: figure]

2. Setup complete, different 3d printer has different USB Serial port, here shows COM13


Click here to set the printer


1. Select the USB serial
port ,Different 3D printer shows different port number
2. The Baud Rate is 115200

If you don’t know the port number, Right click “My computer”-“ Management”- “Device manager”-“Port” ,find the number.)


Set the temperature according to material ABS or PLA.

Reference Temp.：
ABS extruder: 230℃
Heated bed: 80~90℃

PLA extruder: 200℃
Heated bed: 55~60℃


The Afinibot A3 print area set as picture.

After setting all , click “OK”.

170


Step 1: Load a print object


Step 2: Select Slic3r, and then click Configure


# Parameters setting system

Step 3: Set
parameters

Layer height can be 0.1mm to 0.4mm, usually 0.2mm
First layer height should be less or equal other layer height.


Density of internal infill , expressed in the range 0-1 (default:0.4)


Remember to save the
changes and rename


Filament diameter is 1.75mm, One extruder

PLA filament temperature is 200℃ Bed 55℃


Select “keep fan always on”


Remember to save the
changes and rename


The print size is
200*200*170mm, you
can set as picture

The nozzle diameter is
0.4mm


Remember to save the
changes and rename


Turn off the window
after saving


Step 4: Select the parameters which you set and named from slic3r


Slicing

Step 4: Click “Slice with Slic3r”


You can click here and
save the gcode file
Micro SD card

Please refer to the file <<How to off-line print > > to study how to print a model using a micro-SD Card.


Step 5: Connect to the 3D
printer and Run job

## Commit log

2020-09-30 Added firmware
    [Configuration.h]
2020-09-30 Added USB drivers
2020-09-30 Added parts
    [3D printer spacer v3.stl, v3 End stop for X Idler with laser mount.stl, v6 Adjusted Prusa i3 X Motor.stl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]
